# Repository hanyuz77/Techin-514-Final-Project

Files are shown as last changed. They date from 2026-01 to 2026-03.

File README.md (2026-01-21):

# Techin-514-Final-Project

# Plant Watering Detection
This is a two-device system that helps plant owners understand soil moisture.  
A soil sensor sends moisture estimates over BLE to a stepper-driven gauge that gently indicates **Dry → Okay → Overwatered**, with a soft LED and a calibration button.

## 1) Overall Concept 
**What it does:** This system measures soil moisture in a plant pot and displays the reading on a physical analog gauge with a stepper motor needle and color-changing LED. The sensor unit wirelessly transmits moisture data via Bluetooth Low Energy (BLE) to the display gauge, which shows soil wetness on a traditional meter-style dial.

**Physical Features:**
 The system consists of two battery-powered devices: (1) a compact sensor unit with a stake-style enclosure that sits at the soil surface with the moisture probe inserted into the soil, and (2) a desktop analog gauge featuring a rotating needle (driven by stepper motor), RGB LED indicator, and calibration button housed in a circular meter-style enclosure with a custom PCB.

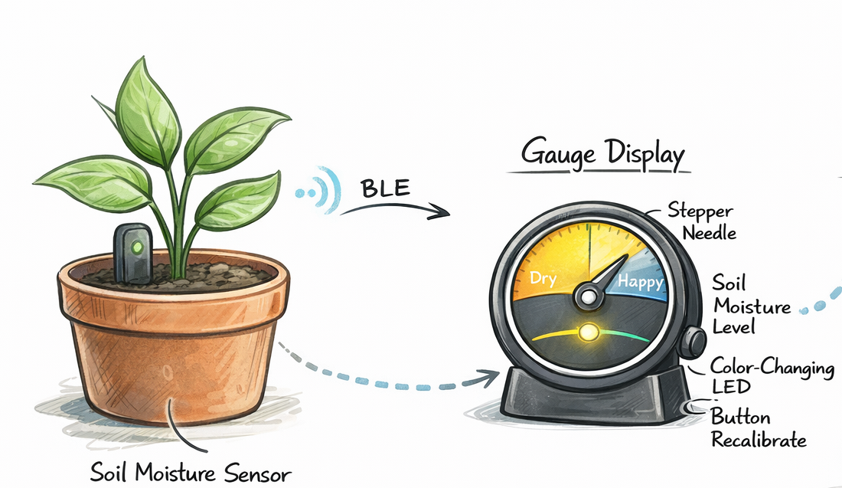
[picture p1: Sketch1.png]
sketch1


## 2) Sensor Device
**Device:** Soil Sensor (in/near the plant pot)

**How it works:**
- A capacitive soil moisture probe outputs an analog voltage correlated with moisture.
- The ESP32-C3 samples the analog value, applies smoothing (moving average / EMA), converts it into a normalized `moisture_score (0–100)`, and transmits it over BLE at a low duty cycle to save power.

**Components:**
- Seeed Studio XIAO ESP32C3
- Capacitive Soil Moisture Sensor v1.2: Corrosion-resistant analog sensor (0-3.3V output proportional to moisture)
- RC Low-Pass Filter: 10kΩ resistor + 0.1µF capacitor for analog signal smoothing (cutoff ~159 Hz)
- 1S LiPo Battery: 3.7V 500-1000mAh lithium polymer with JST connector
- SPST Power Switch: Slide or toggle switch for ON/OFF
- Power LED: 3mm red LED with 1kΩ resistor
- Enclosure: 3D-printed stake-top box with cable gland for sensor wire

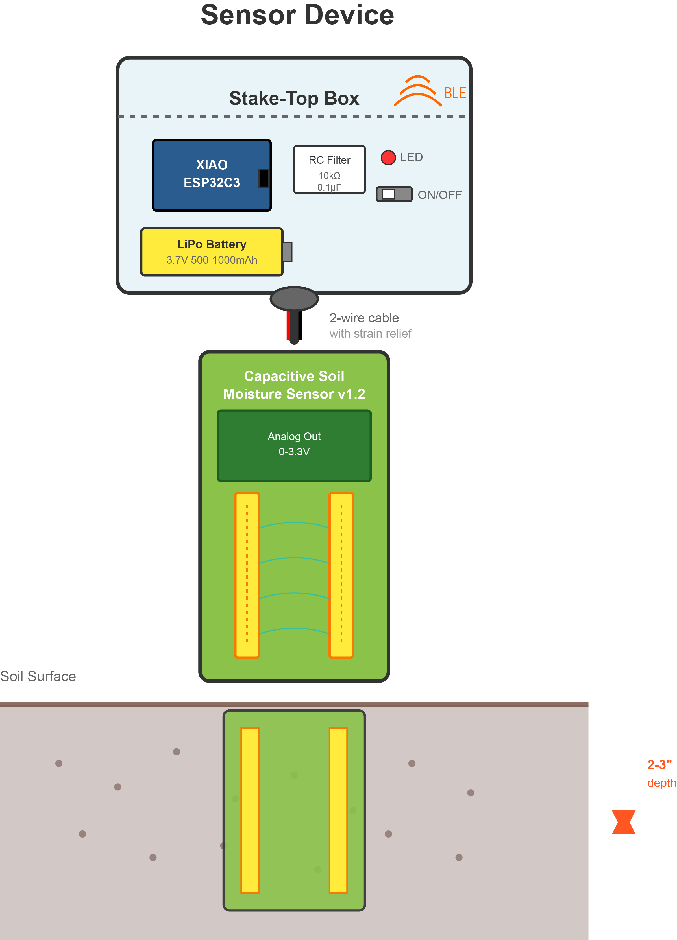
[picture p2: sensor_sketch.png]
sensor


## 3) Display Device
**Device:** Gauge Display Node (physical needle + LED + button)

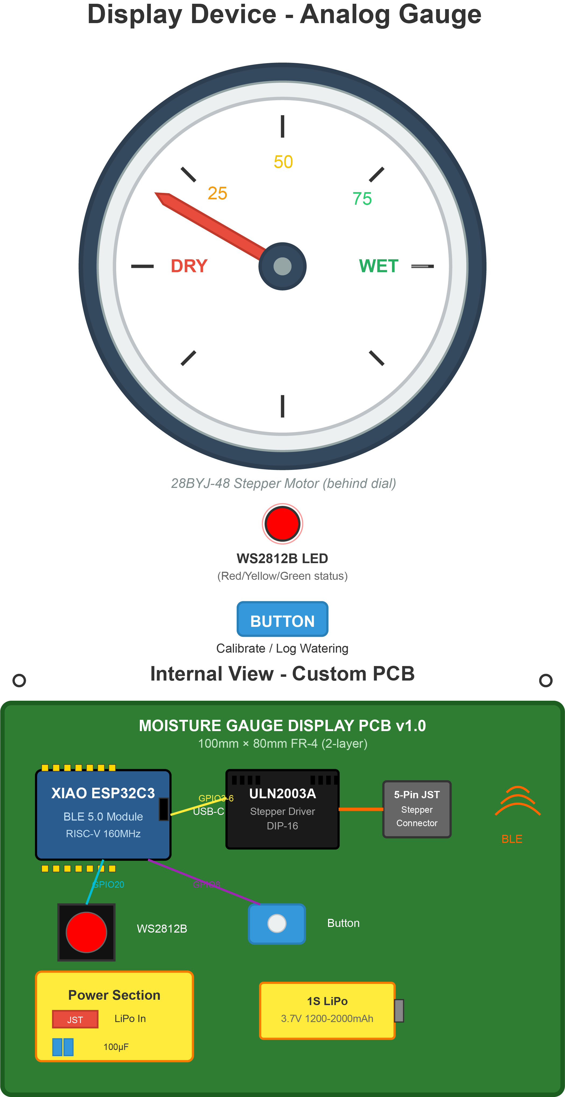
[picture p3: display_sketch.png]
display


**How it works:**
- The display receives `moisture_score` via BLE and maps it to a needle angle (e.g., 0–180°) with hysteresis to prevent jitter.
- One button triggers calibration and/or logs watering; one LED provides a cue.

**Components:**
- Seeed Studio XIAO ESP32C3 (Part: 102010388): Same MCU as sensor unit, acts as BLE receiver
- 28BYJ-48 5V Stepper Motor (Part: 28BYJ-48): Geared stepper motor with 1:64 reduction ratio, ~2048 steps per revolution, includes needle attachment
- ULN2003A Darlington Array (Part: ULN2003A, DIP-16 or SOT23): Stepper motor driver IC, typically on pre-made driver board
- WS2812B RGB LED (Part: WS2812B, 5050 package): Individually addressable smart LED with integrated driver
- Tactile Switch (Part: Generic 6×6mm momentary): Calibration/logging button with internal or external pull-up
- 1S LiPo Battery: 3.7V 1200-2000mAh to handle stepper motor current draw (~150mA when moving)
- Custom PCB: Two-layer FR-4 board integrating all components with mounting holes for stepper motor

**Custom PCB plan:**
- A custom PCB will be designed for the display node integrating MCU headers, ULN2003A stepper driver, WS2812B LED, button, and power connectors.

## 4) Communication + System Diagram

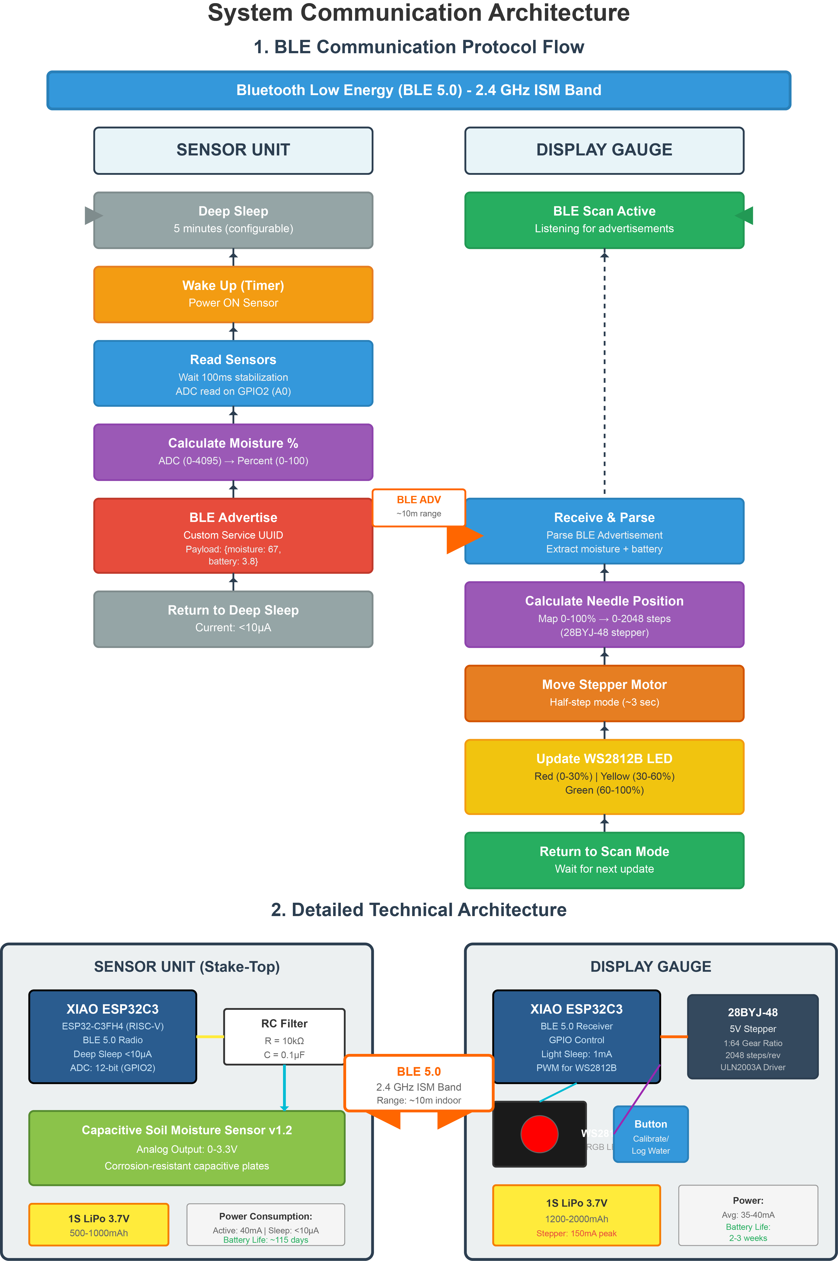
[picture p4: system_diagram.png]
diagram


## Parts List with Part Numbers

### Sensor Unit Components

| Component | Part Number / Description | Qty | Notes |
|---|---|-----|---|
| Microcontroller | Seeed Studio XIAO ESP32C3 (SKU: 102010388) | 1 | ESP32-C3FH4 chip, BLE 5.0, WiFi |
| Soil Sensor | Capacitive Soil Moisture Sensor v1.2 | 1 | Analog output, corrosion-resistant |
| Resistor | 10kΩ ±5% 1/4W carbon film | 1 | RC filter component |
| Capacitor | 0.1µF (100nF) ceramic 50V | 1 | RC filter component |
| Power LED | 3mm Red LED (2V, 20mA) | 1 | Optional status indicator |
| LED Resistor | 1kΩ ±5% 1/4W | 1 | Current limiting for power LED |
| Battery | 1S LiPo 3.7V 500-1000mAh with JST connector | 1 | E.g., Adafruit #328 or similar |
| Switch | SPST slide or toggle switch | 1 | ON/OFF power control |
| Wire | 22AWG stranded 2-conductor cable | 1m | Sensor to board connection |
| Enclosure | 3D printed stake box 60×40×25mm | 1 | STL file provided in repo |
| Cable Gland | PG7 or M12 strain relief fitting | 1 | Waterproof cable entry |

---

### Display Unit Components

| Component | Part Number / Description | Qty | Notes |
|---|---|-----|---|
| Microcontroller | Seeed Studio XIAO ESP32C3 (SKU: 102010388) | 1 | Same as sensor unit |
| Stepper Motor | 28BYJ-48 5V stepper with gear reduction | 1 | 1:64 ratio, ~2048 steps/rev |
| Stepper Driver | ULN2003A DIP-16 IC | 1 | Or pre-made ULN2003 driver board |
| RGB LED | WS2812B 5050 package (NeoPixel) | 1 | Individually addressable |
| Button | 6×6mm tactile switch, momentary | 1 | Through-hole or SMD |
| Battery | 1S LiPo 3.7V 1200-2000mAh JST | 1 | Higher capacity for stepper |
| Custom PCB | FR-4 2-layer 100×80mm | 1 | Design files in repo |
| Resistor (LED) | 470Ω ±5% 1/4W | 1 | If needed for WS2812B data line |
| Resistor (Button) | 10kΩ ±5% 1/4W | 1 | External pull-up if not using internal |
| Capacitor (Bypass) | 100µF electrolytic 16V | 1 | Power supply smoothing for stepper |
| Capacitor (Decoupling) | 0.1µF ceramic 50V | 3 | Per IC/module |
| Pin Headers | 2.54mm female socket (for XIAO) | 2 | 7-pin each side |
| Connector | 5-pin JST XH or equiv (stepper) | 1 | To 28BYJ-48 |
| Enclosure | Circular meter housing 120mm dia | 1 | 3D printed or modified analog meter |
| Dial Face | Printed paper/plastic 100mm | 1 | Moisture scale 0-100% |
| Needle | 3D printed or metal pointer | 1 | Attaches to stepper shaft |

---

### Common Components & Tools

| Item | Description | Qty | Notes |
|---|---|-----|---|
| Breadboard wires | Male-to-male/female jumper wires | 1 set | For prototyping |
| Heat shrink tubing | Assorted sizes 2-6mm | 1 set | Wire insulation |
| M2 screws | M2×6mm screws | 4 | PCB mounting |
| M3 screws | M3×10mm screws | 2 | Stepper motor mounting |
| JST connectors | 2-pin JST connectors for batteries | 2 | Power connections |
| USB-C cable | USB-C to USB-A programming cable | 1 | For XIAO programming |

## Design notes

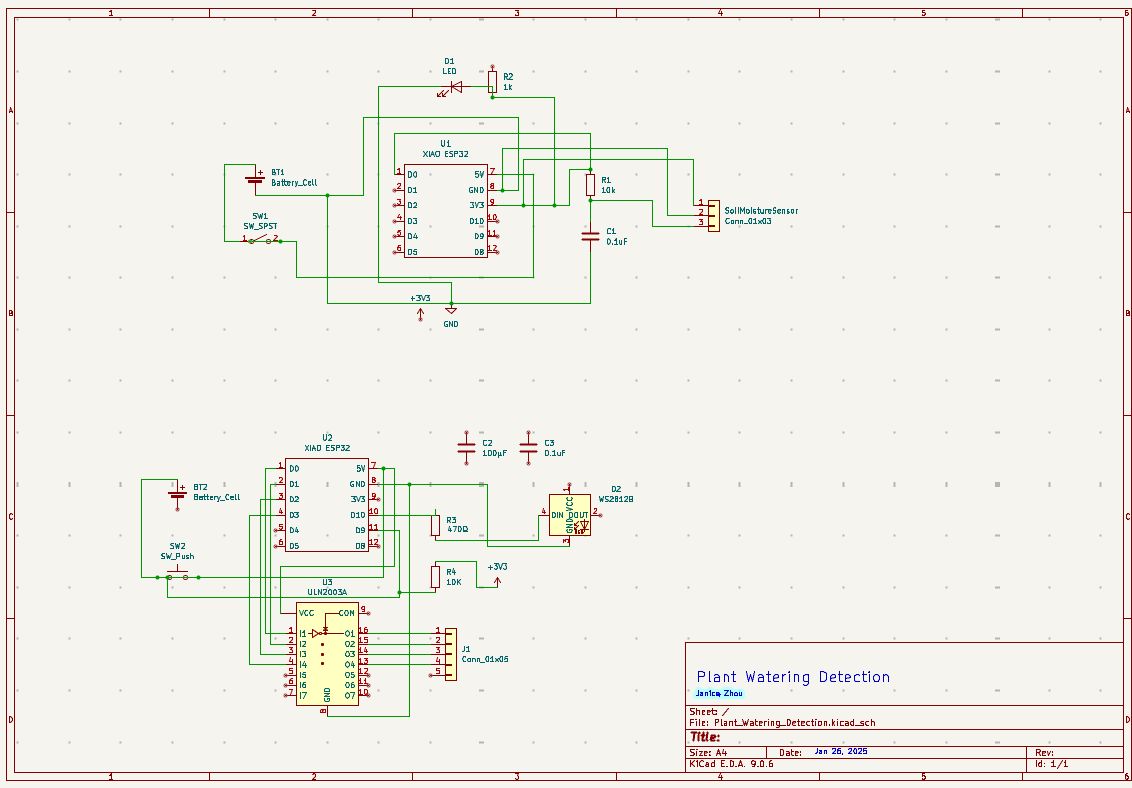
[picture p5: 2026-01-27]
Schematic.png

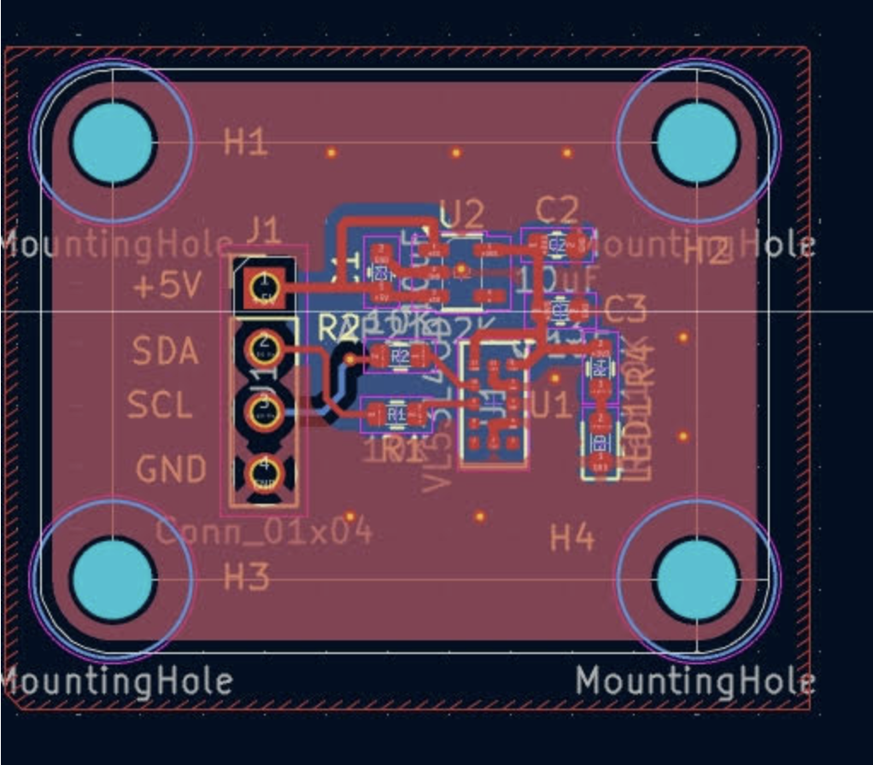
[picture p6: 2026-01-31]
TECHIN514_w26_project_PCB/Screenshot 2026-01-31 at 3.56.07 PM.png

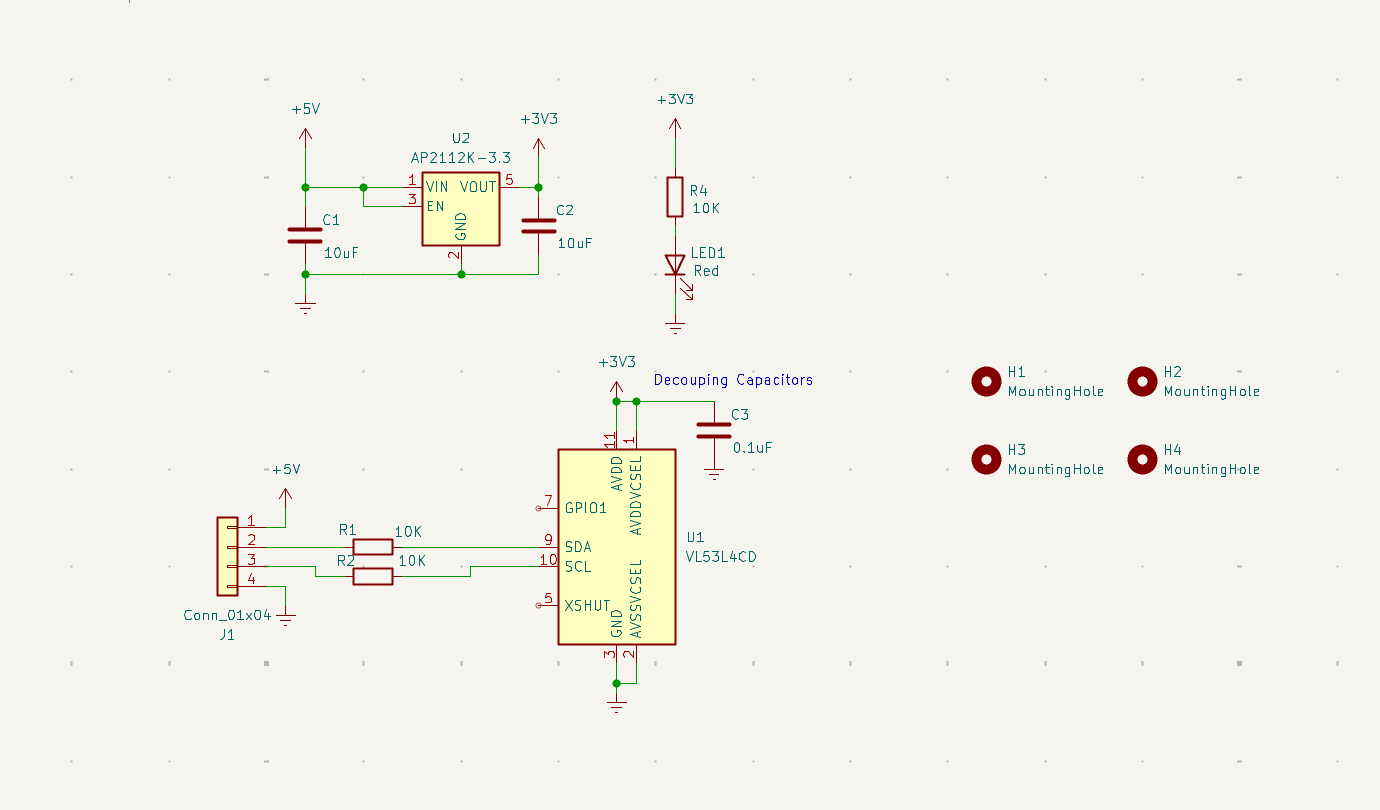
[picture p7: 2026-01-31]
TECHIN514_w26_project_PCB/Screenshot 2026-01-31 at 3.58.21 PM.png

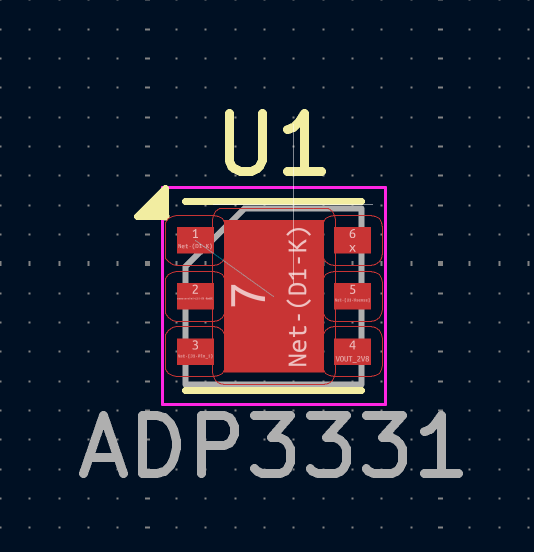
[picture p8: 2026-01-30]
TECHIN514_w26_project_PCB/Screenshot 2026-01-29 at 10.50.48 PM.png

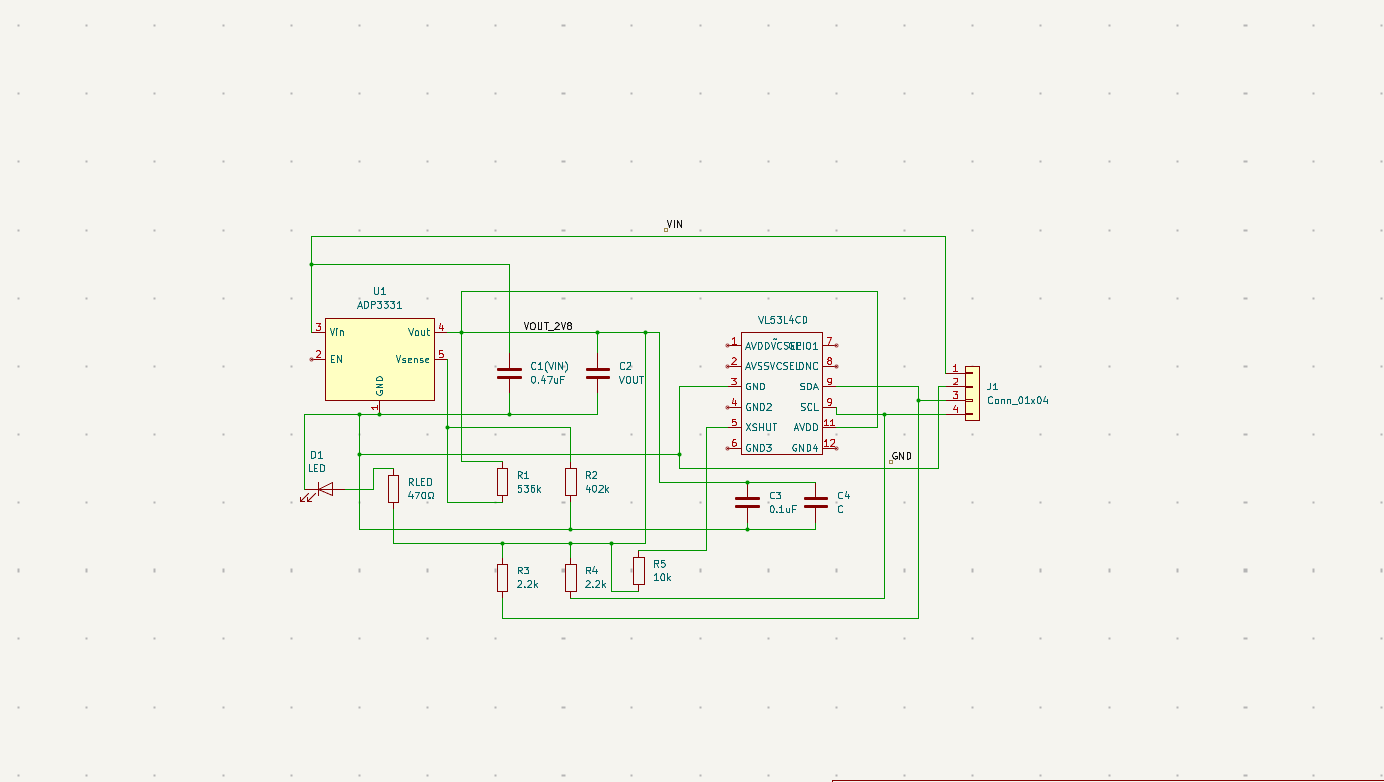
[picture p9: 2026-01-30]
TECHIN514_w26_project_PCB/Screenshot 2026-01-29 at 10.31.52 PM.png

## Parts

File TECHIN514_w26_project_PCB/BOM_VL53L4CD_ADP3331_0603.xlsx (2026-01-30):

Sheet: BOM
Line | RefDes | Qty | Function | Value | Description | MPN | Supplier | Package | KiCad Footprint | Notes
1 | U1 | 1 | Sensor |  | Time-of-Flight (ToF) distance sensor, I²C | VL53L4CDV0DH/1 | DigiKey | Optical LGA12 (4.4×2.4 mm) | Custom: VL53L4CD_LGA12_4.4x2.4mm | Place near board edge; keep optical path clear
2 | U2 | 1 | Regulator |  | LDO regulator, adjustable, 200 mA | ADP3331ARTZ-REEL7 | DigiKey | SOT-23-6 | Package_TO_SOT_SMD:SOT-23-6 | VIN(3–5V) → VOUT_2V8; SD tied to VIN
3 | J1 | 1 | Header |  | Pin header, 1×4, 2.54 mm, vertical | TSW-104-07-F-S | DigiKey | Through-hole | Connector_PinHeader_2.54mm:PinHeader_1x04_P2.54mm_Vertical | Pins: VIN, GND, SDA, SCL
4 | D1 | 1 | LED | Green | LED indication, green, 0603 | APT1608ZGC-AMT | DigiKey | 0603 (1608 Metric) | LED_SMD:LED_0603_1608Metric | Power LED on VOUT_2V8
5 | RLED | 1 | Resistor | 470 Ω | Resistor, 1%, 0.1W | RC0603FR-07470RL | DigiKey | 0603 (1608 Metric) | Resistor_SMD:R_0603_1608Metric | Sets LED current
6 | RPU1,RPU2 | 2 | Resistor | 2.2 kΩ | I²C pull-up resistors, 1%, 0.1W | RC0603FR-072K2L | DigiKey | 0603 (1608 Metric) | Resistor_SMD:R_0603_1608Metric | SDA/SCL pull-ups to VOUT_2V8
7 | RXSHUT | 1 | Resistor | 10 kΩ | XSHUT pull-up resistor, 1%, 0.1W | RC0603FR-0710KL | DigiKey | 0603 (1608 Metric) | Resistor_SMD:R_0603_1608Metric | Default enable sensor
8 | R1 | 1 | Resistor | 536 kΩ | Feedback divider top resistor, 1%, 0.1W | RC0603FR-07536KL | DigiKey | 0603 (1608 Metric) | Resistor_SMD:R_0603_1608Metric | ADP3331 sets ~2.8V output
9 | R2 | 1 | Resistor | 402 kΩ | Feedback divider bottom resistor, 1%, 0.1W | RC0603FR-07402KL | DigiKey | 0603 (1608 Metric) | Resistor_SMD:R_0603_1608Metric | ADP3331 sets ~2.8V output
10 | C1 | 1 | Capacitor | 0.47 µF | Input capacitor, X7R, 10V | CC0603KRX7R6BB474 | DigiKey | 0603 (1608 Metric) | Capacitor_SMD:C_0603_1608Metric | Place next to ADP3331 IN
11 | C2 | 1 | Capacitor | 0.47 µF | Output capacitor, X7R, 10V | CC0603KRX7R6BB474 | DigiKey | 0603 (1608 Metric) | Capacitor_SMD:C_0603_1608Metric | Place next to ADP3331 OUT
12 | C3 | 1 | Capacitor | 0.1 µF | Sensor decoupling capacitor, X7R, 10V | CC0603KRX7R6BB104 | DigiKey | 0603 (1608 Metric) | Capacitor_SMD:C_0603_1608Metric | Place next to VL53L4CD VDD pins
13 | C4 | 1 | Capacitor | 0.47 µF | Sensor bulk capacitor (optional), X7R, 10V | CC0603KRX7R6BB474 | DigiKey | 0603 (1608 Metric) | Capacitor_SMD:C_0603_1608Metric | Optional extra bulk cap near sensor

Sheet: Notes
Assembly / Layout notes
C1 (VIN) and C2 (VOUT) should be placed as close as possible to the ADP3331 pins (small input/output loops).
C3 (0.1uF) should be placed as close as possible to VL53L4CD supply pins; C4 is optional but recommended.
Use a ground plane on the component side (F.Cu) and stitch to bottom ground if you use it.
Label header pins on silkscreen: VIN(3–5V), GND, SDA, SCL. Avoid sharp corners on Edge.Cuts.

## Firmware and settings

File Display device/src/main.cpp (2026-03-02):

#include <Arduino.h>
#include <NimBLEDevice.h>
#include <Adafruit_NeoPixel.h>
#include <AccelStepper.h>
#include <Preferences.h>

// --------------------
// Pin compatibility helpers
// --------------------
#ifndef D0
  #define D0 0
#endif
#ifndef D1
  #define D1 1
#endif
#ifndef D2
  #define D2 2
#endif
#ifndef D3
  #define D3 3
#endif
#ifndef D10
  #define D10 10
#endif
// Button pin is U1 pad10 on your PCB; footprint labels it "10" but it's physically where D9 usually is.
// Try D9 first if your variant defines it; otherwise fall back to 9 or 10-position pin.
// If your build fails because D9 doesn't exist, just change PIN_BTN to 9 (or the GPIO you find).
#ifndef D9
  #define D9 9
#endif

// =====================
// ✅ YOUR PCB PIN MAP
// =====================

// Stepper driver inputs (U2 I1..I4) -> XIAO D0..D3
static const int PIN_STP_IN1 = D0;  // U2 I1
static const int PIN_STP_IN2 = D1;  // U2 I2
static const int PIN_STP_IN3 = D2;  // U2 I3
static const int PIN_STP_IN4 = D3;  // U2 I4

// NeoPixel DIN goes through R3 to XIAO D10
static const int PIN_NEOPIXEL = D10;

// Button SW2 -> Net-(R4-Pad2) -> U1 pad10 (likely D9 position)
static const int PIN_BTN = D9;
static const bool BTN_ACTIVE_LOW = true; // SW2 to GND

// =====================
// BLE UUID (same as earlier)
// =====================
static const NimBLEUUID SERVICE_UUID("6e3a9c1a-4b7b-4e2e-9a1b-9d0f7a0d5d01");

// =====================
// Gauge config
// =====================
static const float ANGLE_MIN_DEG = 0.0f;
static const float ANGLE_MAX_DEG = 180.0f;

// 28BYJ-48 typical
static const int   STEPS_PER_REV = 2048;
static const float DEG_PER_STEP  = 360.0f / (float)STEPS_PER_REV;

// Hysteresis
static const int MOISTURE_HYST = 2;

// Motion tuning
static const float MAX_SPEED = 600.0f;
static const float ACCEL     = 400.0f;

// NeoPixel
static const int N_PIXELS = 1;

// =====================
// Globals
// =====================
Adafruit_NeoPixel pixels(N_PIXELS, PIN_NEOPIXEL, NEO_GRB + NEO_KHZ800);
AccelStepper stepper(AccelStepper::HALF4WIRE, PIN_STP_IN1, PIN_STP_IN3, PIN_STP_IN2, PIN_STP_IN4);
Preferences prefs;

volatile uint8_t  g_moisture = 0;
volatile uint16_t g_battMv   = 0;
volatile bool     g_hasReading = false;

int  g_lastMoistureShown = -999;
long g_zeroOffsetSteps   = 0;

// =====================
// Helpers
// =====================
static long angleDegToSteps(float deg) {
  deg = constrain(deg, ANGLE_MIN_DEG, ANGLE_MAX_DEG);
  return lroundf(deg / DEG_PER_STEP);
}

static float moistureToAngle(uint8_t m) {
  float t = (float)m / 100.0f;
  return ANGLE_MIN_DEG + t * (ANGLE_MAX_DEG - ANGLE_MIN_DEG);
}

static void setLedForMoisture(uint8_t m) {
  uint32_t color;
  if (m < 30)      color = pixels.Color(255, 0, 0);
  else if (m < 60) color = pixels.Color(255, 180, 0);
  else             color = pixels.Color(0, 255, 0);
  pixels.setPixelColor(0, color);
  pixels.show();
}

static bool buttonPressed() {
  int v = digitalRead(PIN_BTN);
  return BTN_ACTIVE_LOW ? (v == LOW) : (v == HIGH);
}

static void flashBlue(uint8_t times) {
  for (uint8_t i=0;i<times;i++) {
    pixels.setPixelColor(0, pixels.Color(0, 80, 255));
    pixels.show();
    delay(120);
    pixels.setPixelColor(0, 0);
    pixels.show();
    delay(120);
  }
}

static void handleButton() {
  static bool wasPressed = false;
  static uint32_t tDown = 0;

  bool pressed = buttonPressed();
  uint32_t now = millis();

  if (pressed && !wasPressed) {
    tDown = now;
    wasPressed = true;
  } else if (!pressed && wasPressed) {
    uint32_t held = now - tDown;
    wasPressed = false;

    if (held > 800) {
      // Long press: calibrate zero
      g_zeroOffsetSteps = stepper.currentPosition();
      prefs.putLong("zero", g_zeroOffsetSteps);
      Serial.printf("[BTN] Calibrated zero at steps=%ld\n", g_zeroOffsetSteps);
      flashBlue(3);
    } else {
      // Short press: cue
      Serial.println("[BTN] Log watering (cue)");
      flashBlue(1);
    }
  }
}

// =====================
// BLE scan callback
// =====================
class AdvCallbacks : public NimBLEAdvertisedDeviceCallbacks {
  void onResult(NimBLEAdvertisedDevice* dev) override {
    if (!dev->isAdvertisingService(SERVICE_UUID)) return;

    std::string mfg = dev->getManufacturerData();
    if (mfg.size() != 5) return;

    const uint8_t* b = (const uint8_t*)mfg.data();
    if (b[0] != 1) return;

    g_moisture = b[1];
    g_battMv = (uint16_t)b[2] | ((uint16_t)b[3] << 8);
    g_hasReading = true;

    Serial.printf("[BLE] moisture=%u battMv=%u rssi=%d\n", g_moisture, g_battMv, dev->getRSSI());
  }
};

static void startScan() {
  NimBLEDevice::init("PlantGauge");
  NimBLEScan* scan = NimBLEDevice::getScan();
  scan->setAdvertisedDeviceCallbacks(new AdvCallbacks(), true);
  scan->setActiveScan(true);
  scan->setInterval(45);
  scan->setWindow(15);
  scan->start(0, nullptr, false); // continuous
  Serial.println("[BLE] scanning...");
}

void setup() {
  Serial.begin(115200);
  delay(200);

  pinMode(PIN_BTN, BTN_ACTIVE_LOW ? INPUT_PULLUP : INPUT);

  pixels.begin();
  pixels.setBrightness(40);
  pixels.show();

  stepper.setMaxSpeed(MAX_SPEED);
  stepper.setAcceleration(ACCEL);

  prefs.begin("gauge", false);
  g_zeroOffsetSteps = prefs.getLong("zero", 0);
  stepper.setCurrentPosition(g_zeroOffsetSteps);
  Serial.printf("[CAL] zero steps=%ld\n", g_zeroOffsetSteps);

  startScan();
}

void loop() {
  handleButton();
  stepper.run();

  if (g_hasReading) {
    g_hasReading = false;

    int m = (int)g_moisture;
    if (abs(m - g_lastMoistureShown) >= MOISTURE_HYST) {
      g_lastMoistureShown = m;

      setLedForMoisture((uint8_t)m);

      float angle = moistureToAngle((uint8_t)m);
      long targetSteps = g_zeroOffsetSteps + angleDegToSteps(angle);

      Serial.printf("[GAUGE] m=%d angle=%.1f targetSteps=%ld\n", m, angle, targetSteps);
      stepper.moveTo(targetSteps);
    }
  }

  delay(5);
}

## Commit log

2026-01-20 Enhance README with project overview and device details
    Added detailed project description and device specifications.
2026-01-21 Fix image filename case in README.md
